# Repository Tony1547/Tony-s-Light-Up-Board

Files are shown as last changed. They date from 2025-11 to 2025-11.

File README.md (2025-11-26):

# Tony-s-Light-Up-Board
Small board i can take to FRC comps

/ BOM : https://docs.google.com/spreadsheets/d/1fGATLPJ2M_kJRIZs2cyqMHB42CdELpvUBpSz-iXdPng/edit?usp=sharing

(CSV in files as well)





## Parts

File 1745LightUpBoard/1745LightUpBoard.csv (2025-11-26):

Reference | Qty | Value | DNP | Exclude from BOM | Exclude from Board | Footprint | Datasheet
A1 | 1 | Arduino_Nano_v3.x |  |  |  | Module:Arduino_Nano | http://www.mouser.com/pdfdocs/Gravitech_Arduino_Nano3_0.pdf
BT1 | 1 | Battery_Cell |  |  |  |  | ~
C1,C3,C5,C6,C7,C8,C9,C10 | 8 | 100nf |  |  |  | Capacitor_SMD:C_0201_0603Metric_Pad0.64x0.40mm_HandSolder | ~
C2,C4 | 2 | 12pf |  |  |  | Capacitor_SMD:C_0201_0603Metric_Pad0.64x0.40mm_HandSolder | ~
C11,C13,C14 | 3 | 1uf |  |  |  | Capacitor_SMD:C_0201_0603Metric_Pad0.64x0.40mm_HandSolder | ~
C12 | 1 | 10uf |  |  |  | Capacitor_SMD:C_0201_0603Metric_Pad0.64x0.40mm_HandSolder | ~
C15,C16 | 2 | 100uf |  |  |  | Capacitor_SMD:C_0201_0603Metric_Pad0.64x0.40mm_HandSolder | ~
D1 | 1 | D |  |  |  | Diode_SMD:D_0201_0603Metric_Pad0.64x0.40mm_HandSolder | ~
D2,D4 | 2 | GREEN |  |  |  | LED_SMD:LED_0201_0603Metric_Pad0.64x0.40mm_HandSolder | ~
D3 | 1 | YELLOW |  |  |  | LED_SMD:LED_0201_0603Metric_Pad0.64x0.40mm_HandSolder | ~
D5 | 1 | RED |  |  |  | LED_SMD:LED_0201_0603Metric_Pad0.64x0.40mm_HandSolder | ~
D6 | 1 | D_Schottky |  |  |  | Diode_SMD:D_0201_0603Metric_Pad0.64x0.40mm_HandSolder | ~
D7,D8,D9,D10,D11,D12,D13,D14,D15,D16,D17,D18,D19,D20,D21,D22,D23,D24,D25,D26 | 20 | NeoPixel_THT |  |  |  | LED_THT:LED_D5.0mm-4_RGB | https://www.adafruit.com/product/1938
J1 | 1 | Conn_02x03_Odd_Even |  |  |  | Connector_IDC:IDC-Header_2x03_P2.54mm_Horizontal | ~
J2 | 1 | USB_C_Receptacle_USB2.0_16P |  |  |  | Connector_USB:USB_C_Receptacle_Palconn_UTC16-G | https://www.usb.org/sites/default/files/documents/usb_type-c.zip
J3,J4 | 2 | Conn_01x03 |  |  |  | Connector_JST:JST_PH_S3B-PH-K_1x03_P2.00mm_Horizontal | ~
Q1 | 1 | AO3401A |  |  |  | AO3401A:SOT23-3
R1 | 1 | 100k |  |  |  | Resistor_SMD:R_0201_0603Metric_Pad0.64x0.40mm_HandSolder | ~
R2,R3 | 2 | 5k1 |  |  |  | Resistor_SMD:R_0201_0603Metric_Pad0.64x0.40mm_HandSolder | ~
R4,R5,R13,R14 | 4 | 330R |  |  |  | Resistor_SMD:R_0201_0603Metric_Pad0.64x0.40mm_HandSolder | ~
R6 | 1 | 10k |  |  |  | Resistor_SMD:R_0201_0603Metric_Pad0.64x0.40mm_HandSolder | ~
R7,R8,R10 | 3 | 4k7 |  |  |  | Resistor_SMD:R_0201_0603Metric_Pad0.64x0.40mm_HandSolder | ~
R9 | 1 | 1k5 |  |  |  | Resistor_SMD:R_0201_0603Metric_Pad0.64x0.40mm_HandSolder | ~
R11 | 1 | 1k |  |  |  | Resistor_SMD:R_0201_0603Metric_Pad0.64x0.40mm_HandSolder | ~
R12 | 1 | 10K |  |  |  | Resistor_SMD:R_0201_0603Metric_Pad0.64x0.40mm_HandSolder | ~
SW1 | 1 | SW_SPST |  |  |  |  | ~
SW2 | 1 | SW_DIP_x06 |  |  |  |  | ~
U1 | 1 | ATMEGA328P-AU |  |  |  | ATMEGA328P_AU:QFP80P900X900X120-32N
U2 | 1 | CH340N |  |  |  | Package_SO:JEITA_SOIC-8_3.9x4.9mm_P1.27mm | https://aitendo3.sakura.ne.jp/aitendo_data/product_img/ic/inteface/CH340N/ch340n.pdf
U3 | 1 | LIS3DH |  |  |  | Package_LGA:LGA-16_3x3mm_P0.5mm_LayoutBorder3x5y | https://www.st.com/resource/en/datasheet/cd00274221.pdf
U4 | 1 | TP4057 |  |  |  | Package_TO_SOT_SMD:TSOT-23-6 | http://toppwr.com/uploadfile/file/20230304/640302a47b738.pdf
U5 | 1 | XC6206PxxxMR |  |  |  | Package_TO_SOT_SMD:SOT-23-3 | https://www.torexsemi.com/file/xc6206/XC6206.pdf
Y1 | 1 | 16Mhz |  |  |  | Crystal:Crystal_SMD_0603-4Pin_6.0x3.5mm_HandSoldering | ~

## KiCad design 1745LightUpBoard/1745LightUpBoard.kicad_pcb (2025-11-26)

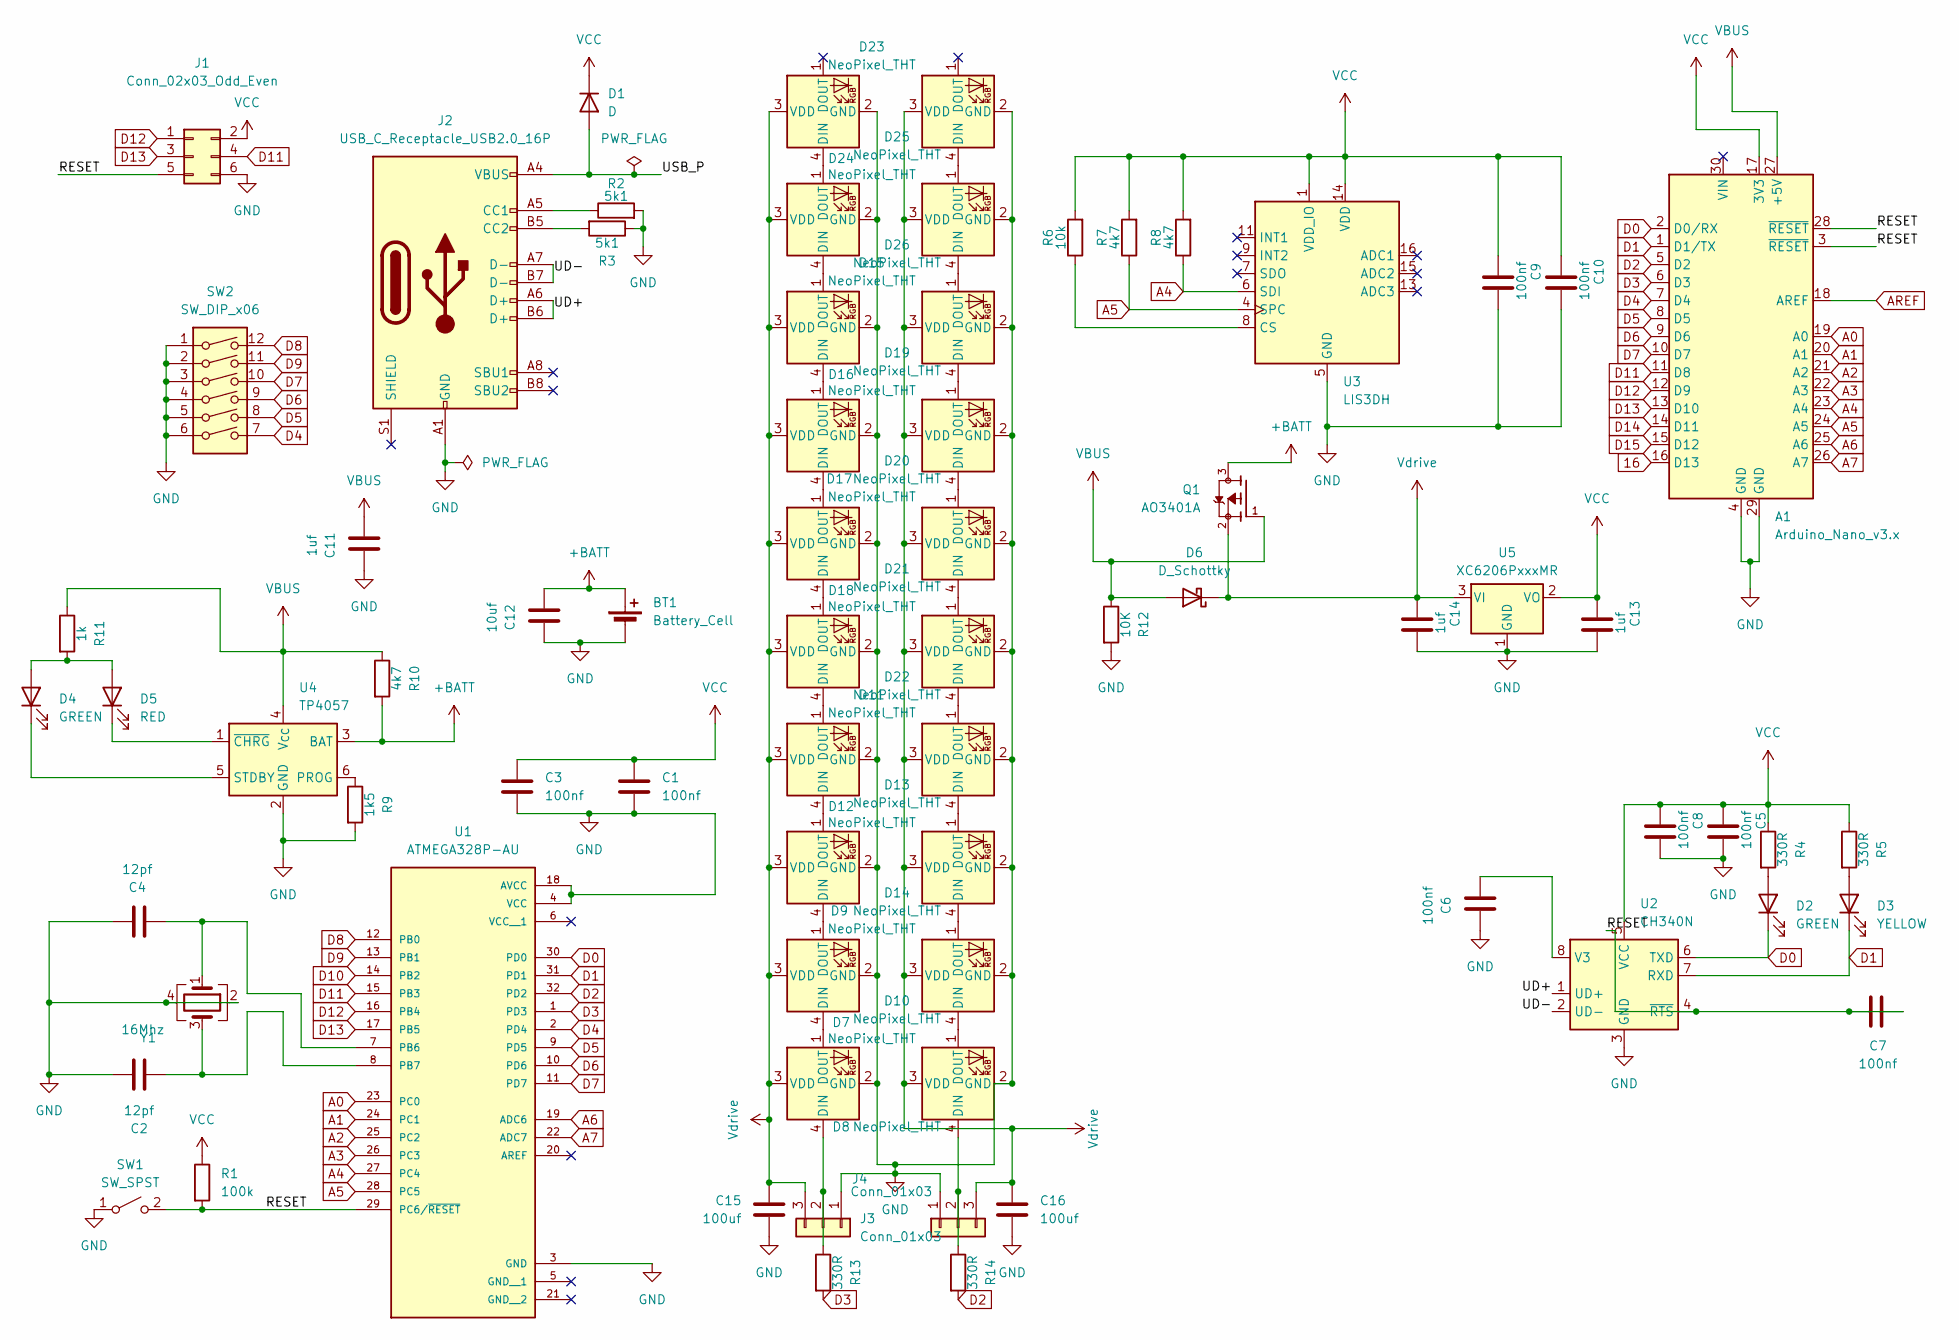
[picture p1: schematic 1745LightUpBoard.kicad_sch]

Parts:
A1: Arduino_Nano_v3.x; Arduino_Nano
BT1: Battery_Cell
C1, C3, C5, C6, C7, C8, C9, C10: 100nf; C_0201_0603Metric_Pad0.64x0.40mm_HandSolder
C2, C4: 12pf; C_0201_0603Metric_Pad0.64x0.40mm_HandSolder
C11, C13, C14: 1uf; C_0201_0603Metric_Pad0.64x0.40mm_HandSolder
C12: 10uf; C_0201_0603Metric_Pad0.64x0.40mm_HandSolder
C15, C16: 100uf; C_0201_0603Metric_Pad0.64x0.40mm_HandSolder
D1: D; D_0201_0603Metric_Pad0.64x0.40mm_HandSolder
D2, D4: GREEN; LED_0201_0603Metric_Pad0.64x0.40mm_HandSolder
D3: YELLOW; LED_0201_0603Metric_Pad0.64x0.40mm_HandSolder
D5: RED; LED_0201_0603Metric_Pad0.64x0.40mm_HandSolder
D6: D_Schottky; D_0201_0603Metric_Pad0.64x0.40mm_HandSolder
D7, D8, D9, D10, D11, D12, D13, D14, D15, D16, D17, D18, D19, D20, D21, D22, D23, D24, D25, D26: NeoPixel_THT; LED_D5.0mm-4_RGB
J1: Conn_02x03_Odd_Even; IDC-Header_2x03_P2.54mm_Horizontal
J2: USB_C_Receptacle_USB2.0_16P; USB_C_Receptacle_Palconn_UTC16-G
J3, J4: Conn_01x03; JST_PH_S3B-PH-K_1x03_P2.00mm_Horizontal
Q1: AO3401A; SOT23-3
R1: 100k; R_0201_0603Metric_Pad0.64x0.40mm_HandSolder
R2, R3: 5k1; R_0201_0603Metric_Pad0.64x0.40mm_HandSolder
R4, R5, R13, R14: 330R; R_0201_0603Metric_Pad0.64x0.40mm_HandSolder
R6: 10k; R_0201_0603Metric_Pad0.64x0.40mm_HandSolder
R7, R8, R10: 4k7; R_0201_0603Metric_Pad0.64x0.40mm_HandSolder
R9: 1k5; R_0201_0603Metric_Pad0.64x0.40mm_HandSolder
R11: 1k; R_0201_0603Metric_Pad0.64x0.40mm_HandSolder
R12: 10K; R_0201_0603Metric_Pad0.64x0.40mm_HandSolder
SW1: SW_SPST
SW2: SW_DIP_x06
U1: ATMEGA328P-AU; QFP80P900X900X120-32N; PARTREV 8271A
U2: CH340N; JEITA_SOIC-8_3.9x4.9mm_P1.27mm
U3: LIS3DH; LGA-16_3x3mm_P0.5mm_LayoutBorder3x5y
U4: TP4057; TSOT-23-6
U5: XC6206PxxxMR; SOT-23-3
Y1: 16Mhz; Crystal_SMD_0603-4Pin_6.0x3.5mm_HandSoldering

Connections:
16: A1.16 (D13)
+BATT: BT1.1 (+), C12.1, Q1.3, R10.2, U4.3 (BAT)
/RESET: A1.3 (~RESET), A1.28 (~RESET), C7.1, C7.2, J1.5, R1.2, SW1.2 (B), U1.29 (PC6/~RESET), U2.4 (~RTS)
/UD+: J2.A6 (D+), J2.B6 (D+), U2.1 (UD+)
/UD-: J2.A7 (D-), J2.B7 (D-), U2.2 (UD-)
/USB_P: D1.2 (A), J2.A4 (VBUS), J2.A9 (VBUS), J2.B4 (VBUS), J2.B9 (VBUS)
A0: A1.19 (A0), U1.23 (PC0)
A1: A1.20 (A1), U1.24 (PC1)
A2: A1.21 (A2), U1.25 (PC2)
A3: A1.22 (A3), U1.26 (PC3)
A4: A1.23 (A4), R8.1, U1.27 (PC4), U3.6 (SDI)
A5: A1.24 (A5), R7.1, U1.28 (PC5), U3.4 (SPC)
A6: A1.25 (A6), U1.19 (ADC6)
A7: A1.26 (A7), U1.22 (ADC7)
AREF: A1.18 (AREF)
D0: A1.2 (D0/RX), D2.1 (K), U1.30 (PD0), U2.6 (TXD)
D1: A1.1 (D1/TX), D3.1 (K), U1.31 (PD1), U2.7 (RXD)
D2: A1.5 (D2), R14.2, U1.32 (PD2)
D3: A1.6 (D3), R13.2, U1.1 (PD3)
D4: A1.7 (D4), SW2.7, U1.2 (PD4)
D5: A1.8 (D5), SW2.8, U1.9 (PD5)
D6: A1.9 (D6), SW2.9, U1.10 (PD6)
D7: A1.10 (D7), SW2.10, U1.11 (PD7)
D8: SW2.12, U1.12 (PB0)
D9: SW2.11, U1.13 (PB1)
D10: U1.14 (PB2)
D11: A1.11 (D8), J1.4, U1.15 (PB3)
D12: A1.12 (D9), J1.1, U1.16 (PB4)
D13: A1.13 (D10), J1.3, U1.17 (PB5)
D14: A1.14 (D11)
D15: A1.15 (D12)
GND: A1.4 (GND), A1.29 (GND), BT1.2 (-), C1.2, C2.2, C3.2, C4.2, C5.2, C6.2, C8.2, C9.2, C10.2, C11.2, C12.2, C13.2, C14.2, C15.2, C16.2, D7.2 (GND), D8.2 (GND), D9.2 (GND), D10.2 (GND), D11.2 (GND), D12.2 (GND), D13.2 (GND), D14.2 (GND), D15.2 (GND), D16.2 (GND), D17.2 (GND), D18.2 (GND), D19.2 (GND), D20.2 (GND), D21.2 (GND), D22.2 (GND), D23.2 (GND), D24.2 (GND), D25.2 (GND), D26.2 (GND), J1.6, J2.A1 (GND), J2.A12 (GND), J2.B1 (GND), J2.B12 (GND), J3.1, J4.1, R2.2, R3.1, R9.2, R12.2, SW1.1 (A), SW2.1, SW2.2, SW2.3, SW2.4, SW2.5, SW2.6, U1.3 (GND), U1.4 (VCC), U1.18 (AVCC), U2.3 (GND), U3.5 (GND), U3.10 (GND), U3.12 (GND), U4.2 (GND), U5.1 (GND), Y1.2, Y1.4
unnamed: D2.2 (A), R4.2
unnamed: D3.2 (A), R5.2
unnamed: D4.2 (A), D5.2 (A), R11.2
unnamed: D4.1 (K), U4.5 (STDBY)
unnamed: D5.1 (K), U4.1 (~CHRG)
unnamed: D7.4 (DIN), J3.2, R13.1
unnamed: D7.1 (DOUT), D9.4 (DIN)
unnamed: D8.4 (DIN), J4.2, R14.1
unnamed: D8.1 (DOUT), D10.4 (DIN)
unnamed: D10.1 (DOUT), D14.4 (DIN)
unnamed: D11.4 (DIN), D12.1 (DOUT)
unnamed: D11.1 (DOUT), D18.4 (DIN)
unnamed: D9.1 (DOUT), D12.4 (DIN)
unnamed: D13.4 (DIN), D14.1 (DOUT)
unnamed: D13.1 (DOUT), D22.4 (DIN)
unnamed: D15.4 (DIN), D16.1 (DOUT)
unnamed: D15.1 (DOUT), D24.4 (DIN)
unnamed: D16.4 (DIN), D17.1 (DOUT)
unnamed: D17.4 (DIN), D18.1 (DOUT)
unnamed: D19.4 (DIN), D20.1 (DOUT)
unnamed: D19.1 (DOUT), D26.4 (DIN)
unnamed: D20.4 (DIN), D21.1 (DOUT)
unnamed: D21.4 (DIN), D22.1 (DOUT)
unnamed: D23.4 (DIN), D24.1 (DOUT)
unnamed: D25.4 (DIN), D26.1 (DOUT)
unnamed: J2.A5 (CC1), R2.1
unnamed: J2.B5 (CC2), R3.2
unnamed: C4.1, U1.7 (PB6), Y1.1
unnamed: C2.1, U1.8 (PB7), Y1.3
unnamed: C6.1, U2.8 (V3)
unnamed: R6.1, U3.8 (CS)
unnamed: R9.1, U4.6 (PROG)
VBUS: A1.27 (+5V), C11.1, D6.2 (A), Q1.1, R10.1, R11.1, R12.1, U4.4 (V_{CC})
VCC: A1.17 (3V3), C1.1, C3.1, C5.1, C8.1, C9.1, C10.1, C13.1, D1.1 (K), J1.2, R1.1, R4.1, R5.1, R6.2, R7.2, R8.2, U2.5 (VCC), U3.1 (VDD_IO), U3.14 (VDD), U5.2 (VO)
Vdrive: C14.1, C15.1, C16.1, D6.1 (K), D7.3 (VDD), D8.3 (VDD), D9.3 (VDD), D10.3 (VDD), D11.3 (VDD), D12.3 (VDD), D13.3 (VDD), D14.3 (VDD), D15.3 (VDD), D16.3 (VDD), D17.3 (VDD), D18.3 (VDD), D19.3 (VDD), D20.3 (VDD), D21.3 (VDD), D22.3 (VDD), D23.3 (VDD), D24.3 (VDD), D25.3 (VDD), D26.3 (VDD), J3.3, J4.3, Q1.2, U5.3 (VI)

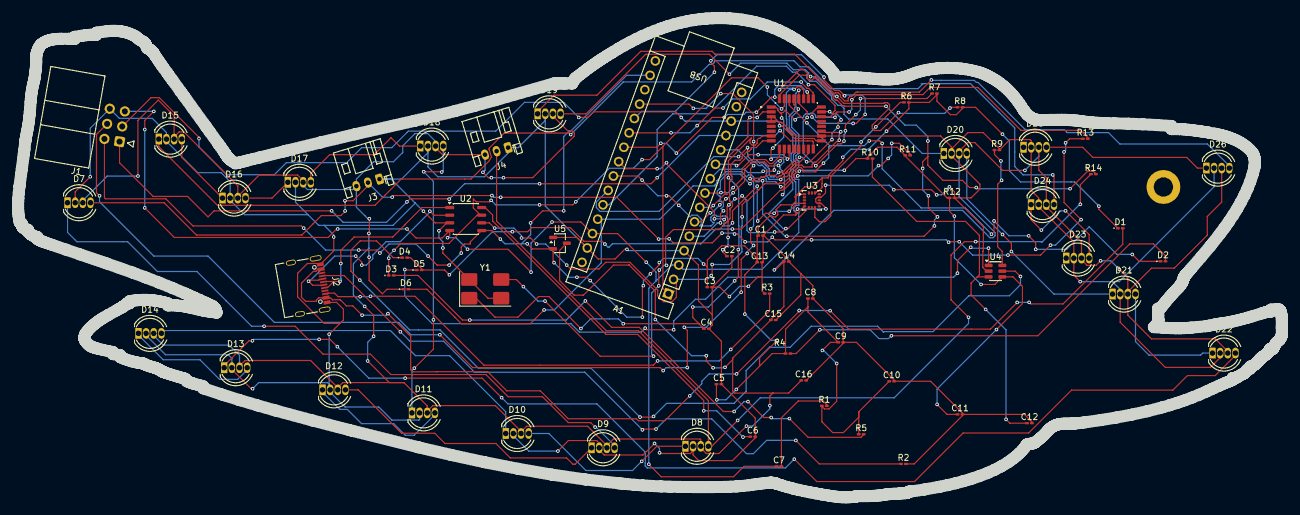
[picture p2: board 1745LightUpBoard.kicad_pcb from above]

Board: 2 copper layers, 209.6 x 79.5 mm, 67 parts (0 on the bottom side), 60 nets.
